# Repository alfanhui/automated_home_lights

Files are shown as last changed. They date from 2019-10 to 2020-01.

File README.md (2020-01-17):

# automated_home_lights
An arduino project to control 3 relay mains switches when entering a room. Controls for current ambient light, detection of direction of travel by a PIR sensor and a door magnet switch. 

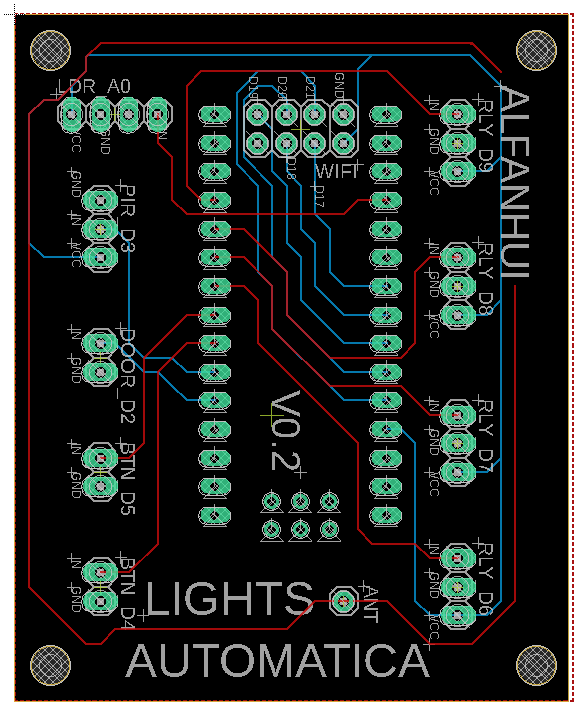
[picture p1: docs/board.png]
Board Schematic


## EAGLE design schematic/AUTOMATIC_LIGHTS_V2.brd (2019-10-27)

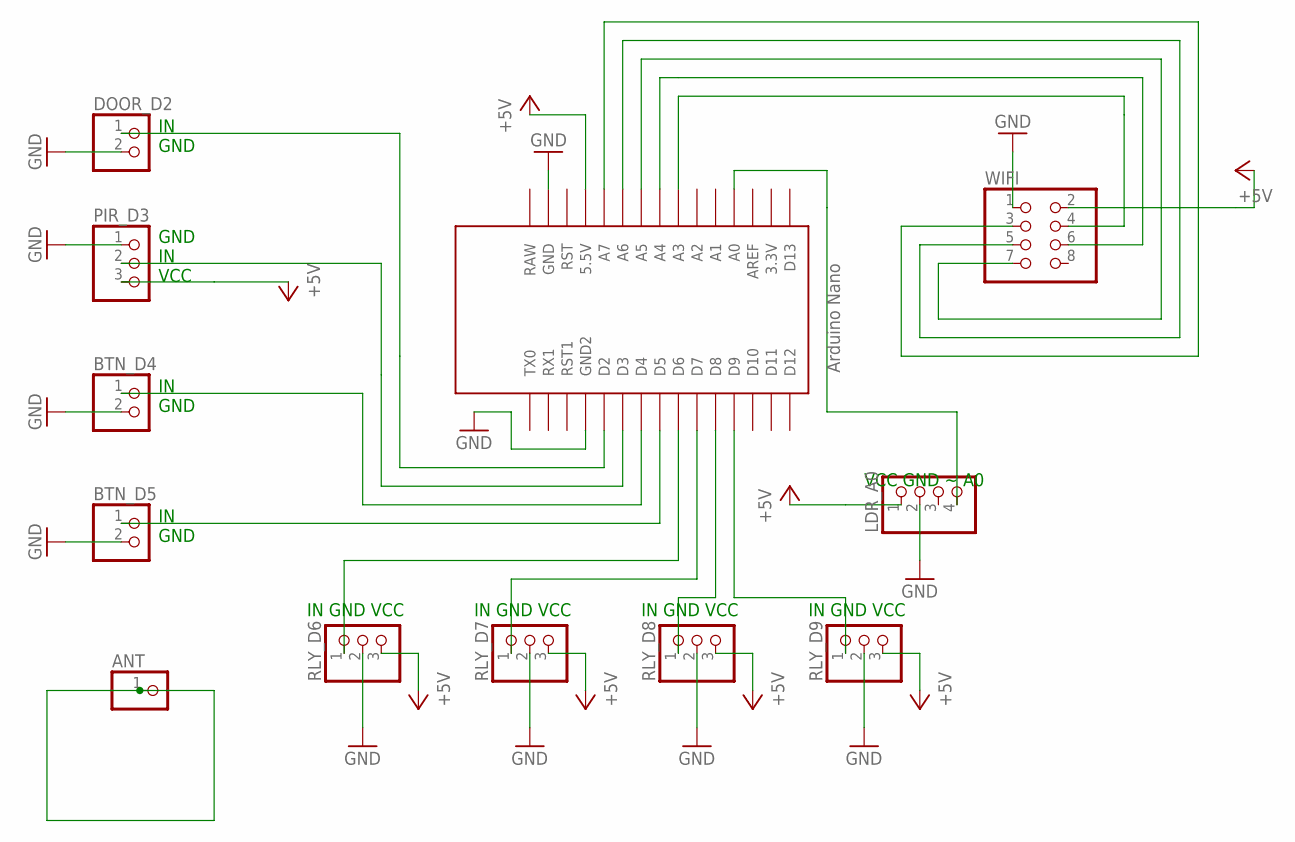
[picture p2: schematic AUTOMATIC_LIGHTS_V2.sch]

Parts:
ANT: PINHD-1X1; 1X01
BTN_D4, BTN_D5: PINHD-1X2; 1X02
DOOR_D2: PINHD-1X2; 1X02
LDR_A0: PINHD-1X4; 1X04
PIR_D3: PINHD-1X3; 1X03
RLY_D6, RLY_D7, RLY_D8, RLY_D9: PINHD-1X3; 1X03
U$1: NANO
WIFI: PINHD-2X4; 2X04

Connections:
+5V: LDR_A0.1, PIR_D3.3, RLY_D6.3, RLY_D7.3, RLY_D8.3, RLY_D9.3, U$1.5V (5.5V), WIFI.2
GND: BTN_D4.2, BTN_D5.2, DOOR_D2.2, LDR_A0.2, PIR_D3.1, RLY_D6.2, RLY_D7.2, RLY_D8.2, RLY_D9.2, U$1.GND, U$1.GND1 (GND2), WIFI.1
unnamed: LDR_A0.4, U$1.A0
unnamed: BTN_D4.1, U$1.D4
unnamed: BTN_D5.1, U$1.D5
unnamed: DOOR_D2.1, U$1.D2
unnamed: PIR_D3.2, U$1.D3
unnamed: RLY_D6.1, U$1.D6
unnamed: RLY_D7.1, U$1.D7
unnamed: RLY_D8.1, U$1.D8
unnamed: RLY_D9.1, U$1.D9
unnamed: U$1.A7, WIFI.3
unnamed: U$1.A6, WIFI.5
unnamed: U$1.A5, WIFI.7
unnamed: U$1.A3, WIFI.4
unnamed: U$1.A4, WIFI.6

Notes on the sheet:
IN GND VCC
IN GND
VCC GND ~ A0
GND IN VCC

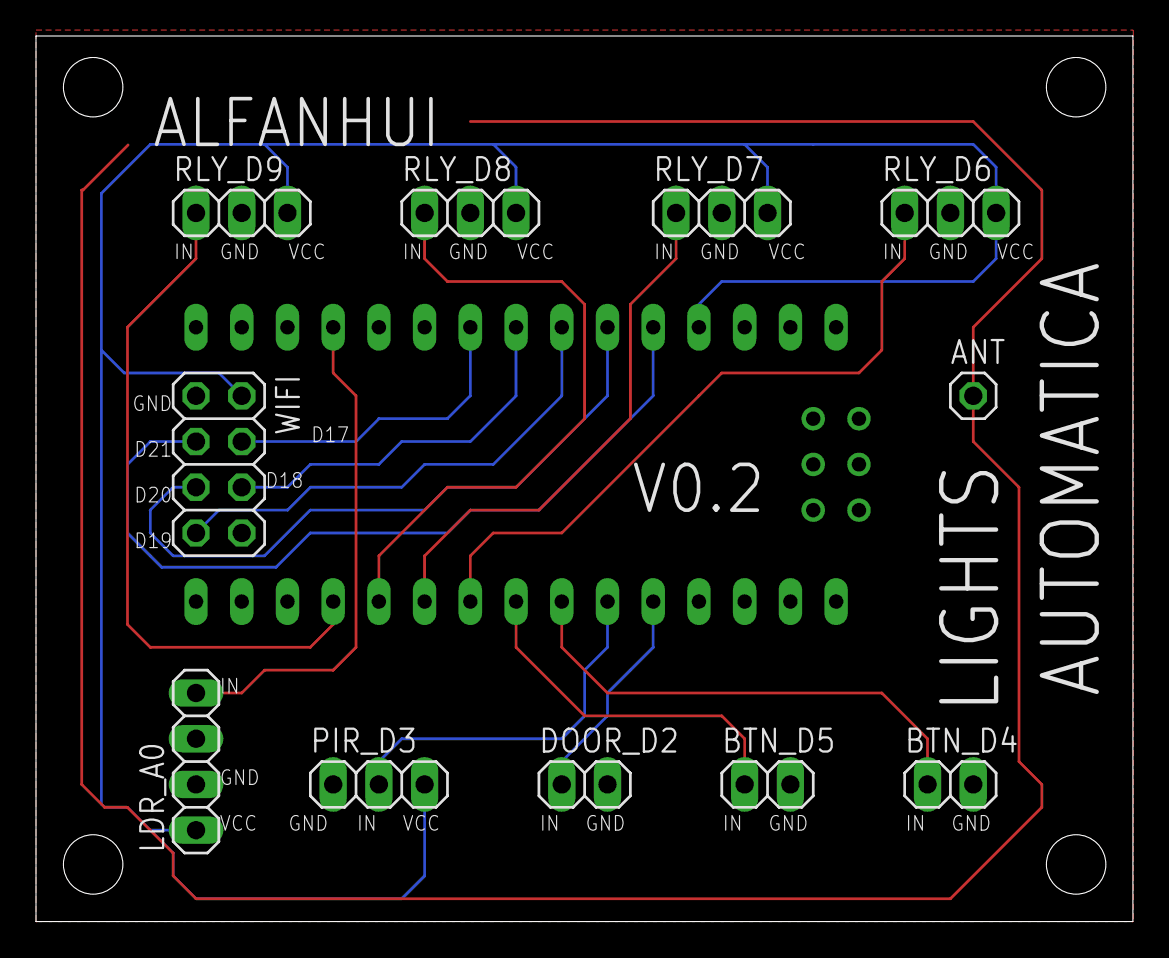
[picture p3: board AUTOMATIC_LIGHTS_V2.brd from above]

Board: 2 copper layers, 60.9 x 49.2 mm, 12 parts (1 on the bottom side), 16 nets.

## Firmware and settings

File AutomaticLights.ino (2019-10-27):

/*
   Written by Stuart Huddy on 13th of March, 2018
   Equipment: Arduino Uno,
              3x 5v relay switches,
              PIR sensor,
              PhotoCell sensor,
              Magnet Door switch,
              Master Button,
              Mini breadboard
   Using the Door magnet with a PIR sensor on one side of the door, I determin the direction of movement
   by checking which action happened first between the PIR and door magenet.
   I have 3 relays, one controlling the main light switch, and 2 lamps for chilled lighting. The chilled
   lighting turns on after a minute and a half of entering the room.
*/


#include <elapsedMillis.h>

//Pin values
const int LIGHT_DETECT_PIN = A0;
const int BUTTON = 12;
const int PIR_PIN = 3;
const int DOOR_PIN = 2;
const int RELAY_MAIN_PIN = 7;
const int RELAY_LAMP1_PIN = 8;
const int RELAY_LAMP2_PIN = 10;


//temp varaibles
unsigned int light_detect_raw = 0;
int button_state = 0;
int pir_raw = 0;
int door_state = 0;

//deciders
bool lights_on = false;  //True when lights are on
bool entered = true;     //True when someone enteres
bool hasLeft = true;     //True when someone leaves, if not reactivated by motion in room
bool initalLightStage = false; //True when first light is turned on

//Timelogs
#define ONE_HALF 90000  //1.5 minutes in milliseconds
#define THREE 180000  //3 minutes in milliseconds
#define NINE 540000 //9 minutes in milliseconds
#define TEN 600000  //10 minutes in milliseconds
#define ELEVEN 660000  //11 minutes in milliseconds
#define THIRTEEN 780000 //13 minutes in milliseconds
#define TOO_DARK 800 //Photosensor trigger  (900 dark, 180 bright)
elapsedMillis timeElapsed_door = 1000;
elapsedMillis timeElapsed_pir;
elapsedMillis timeElapsed_forLampSwitchOver;
elapsedMillis timeElapsed_afterLeaving = 200000;

void setup() {
  Serial.begin(9600);
  //PIR
  attachInterrupt(digitalPinToInterrupt(PIR_PIN), motion_detected, RISING);
  //RELAY
  pinMode(RELAY_MAIN_PIN, OUTPUT);
  pinMode(RELAY_LAMP1_PIN, OUTPUT);
  pinMode(RELAY_LAMP2_PIN, OUTPUT);
  digitalWrite(RELAY_MAIN_PIN, LOW);
  digitalWrite(RELAY_LAMP1_PIN, LOW);
  digitalWrite(RELAY_LAMP2_PIN, LOW);
  //DOOR
  pinMode(DOOR_PIN, INPUT);
  //LIGHT
  pinMode(LIGHT_DETECT_PIN, INPUT);
  //BUTTON
  pinMode(BUTTON, INPUT_PULLUP);
}

void loop() {  
  //printValues();
  //Check state of button
    if(button_state != digitalRead(BUTTON)){
      button_state = digitalRead(BUTTON);
       if(button_state == LOW){
        button_pressed();
      }
    }
    
  //Check if door state has changed.
  if (door_state != digitalRead(DOOR_PIN)) {
    door_state = digitalRead(DOOR_PIN);
    if (door_state == HIGH) {
      timeElapsed_door = 0;
      //Serial.println("DOOR OPEN");
    } else {
      //Serial.println("DOOR CLOSED");
    }
  }

  //Determin movement direction
  if (entered && timeElapsed_door < timeElapsed_pir) {
    //Serial.println("you left the room");
    entered = false;
    if (lights_on) {
      timeElapsed_afterLeaving = 0;
      hasLeft = true;
    }
  } else if (!entered && timeElapsed_door > timeElapsed_pir) {
    int diffBetweenSensors = timeElapsed_door - timeElapsed_pir;
    if(diffBetweenSensors < ELEVEN){ //Stops random shakes of sensor tripping sensor, or wakes in the night
      //Serial.println("you entered the room");
      entered = true;
      if (lights_on) {
        hasLeft = false;
        timeElapsed_afterLeaving = 200000;
      } else {
        if (checkIfDarkEnough()) {
          lights_on = true;
          turnOnMainLighting();
          timeElapsed_forLampSwitchOver = 0;
          initalLightStage = true;
        }
      }
    }
  }

  //Switches to chilled lighting
  if (lights_on && initalLightStage && timeElapsed_forLampSwitchOver > ONE_HALF) {
    turnOnChilledLighting();
  }

  //Switches lights off after leaving
  if (!entered && lights_on && hasLeft && timeElapsed_afterLeaving > TEN) {
    turnOffLighting(true);
    initalLightStage = true;
    hasLeft = false;
    lights_on = false;
  }
}

bool checkIfDarkEnough(){
  light_detect_raw = analogRead(LIGHT_DETECT_PIN);
  //Serial.println(light_detect_raw);
  return (light_detect_raw > TOO_DARK);
}

void turnOnMainLighting(){
     //Serial.println("Turning main lights on");
     digitalWrite(RELAY_MAIN_PIN, HIGH);
}

void turnOnChilledLighting(){
    //Serial.println("Turning chillded lights on");
    digitalWrite(RELAY_LAMP2_PIN, HIGH);
    delay(500); //for effect?
    digitalWrite(RELAY_LAMP1_PIN, HIGH);
    delay(500);
    digitalWrite(RELAY_MAIN_PIN, LOW);
}

void turnOffLighting(bool slowly){
    //Serial.println("Turning all lights off");
    digitalWrite(RELAY_MAIN_PIN, LOW);
    if(slowly) delay(500);
    digitalWrite(RELAY_LAMP1_PIN, LOW);
    if(slowly) delay(500);
    digitalWrite(RELAY_LAMP2_PIN, LOW);
}


//Is called when motion is detected
void motion_detected() {
  //Serial.println("Motion detected");
  if(timeElapsed_door < 6000){
    timeElapsed_pir = 0;
  }
  if(timeElapsed_afterLeaving < THIRTEEN && timeElapsed_afterLeaving > TEN){
    if(checkIfDarkEnough()){
      timeElapsed_pir = 0;
      hasLeft = false;
      turnOnChilledLighting();
      lights_on = true;
    }
  }
  if (lights_on) {
    timeElapsed_pir = 0;
    hasLeft = false;
  }
}

void button_pressed() {
  //Serial.println("Button has been pressed");
  if (lights_on) {
    turnOffLighting(false);
    delay(2000); //Delay to give a chance to block sensor turning lights back on.
    button_state = HIGH;
    entered = false;
    timeElapsed_afterLeaving = ELEVEN;
    timeElapsed_door = 7001;
    timeElapsed_pir = 18000;
    lights_on = false;
  } else {
    turnOnChilledLighting();
    entered = true;
    lights_on = true;
  }
  initalLightStage = false;
  hasLeft = false; //we want this false here so the lights do not reactivate through motion instantly.
  timeElapsed_afterLeaving = 200000;
}


void printValues(){
  Serial.println("timeElapsed_door : timeElapsed_pir : timeElapsed_forLampSwitchOver : timeElapsed_afterLeaving"); 
  Serial.print(timeElapsed_door);
  Serial.print(" : "); 
  Serial.print(timeElapsed_pir);
  Serial.print(" : "); 
  Serial.print(timeElapsed_forLampSwitchOver);
  Serial.print(" : "); 
  Serial.print(timeElapsed_afterLeaving);
  Serial.println();
  Serial.println("lights_on : entered : hasLeft : initialLightStage"); 
  Serial.print(lights_on);
  Serial.print(" : "); 
  Serial.print(entered);
  Serial.print(" : "); 
  Serial.print(hasLeft);
  Serial.print(" : "); 
  Serial.print(initalLightStage);
  Serial.println();
  Serial.println("button_state : light_detect_raw : door_state");
  button_state = digitalRead(BUTTON);
  light_detect_raw = analogRead(LIGHT_DETECT_PIN);
  door_state = digitalRead(DOOR_PIN);
  Serial.print(button_state);
  Serial.print(" : "); 
  Serial.print(light_detect_raw);
  Serial.print(" : "); 
  Serial.print(door_state); 
  Serial.println();
}

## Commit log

2018-03-14 First draft, button code untested as not currently wired.
2018-03-25 Added the button to the circuit, updated button code to work better
2018-04-09 Checked the difference between sensors when detected entered room. Should stop random house shuddering or ghosts from activating the sensor causing it to think someone has entered the room.
2018-04-14 Still coming home to lights on. Its either because the direction of travel is not confirmed and therefore gets triggered, or that the values are not reset correctly when operating master switch. Hope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
    [AutomaticLights.ino]
2018-06-03 Clean up some variable resets. Hopefully bug fixed re: motion not detecting someone is still in room when someone else has left (and for the lights to remain on).
    [AutomaticLights.ino]
2018-06-05 3 conditions added to the button. if the light has been detected within a minute of door opening(generous timing) -> reset timer (to turn on lights), or if the hasLeft timer is between 9 and 13 minut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
    [AutomaticLights.ino]
2018-06-12 Previous commit was had the wrong bool value set.
    [AutomaticLights.ino]
2018-06-13 Refactoring, previous previous previous commit never actually worked, so hopefully when the sensor thinks I've left but then detects me in the room, it will switched to the cool chilled moood lightin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
2019-10-27 Added updated program that has TOO_DARK var and adjustments to lights turning back when they shouldn't
    [AUTOMATIC_LIGHTS_V2.brd, AUTOMATIC_LIGHTS_V2.sch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]
2020-01-17 Updated gitignore and added photo of schematic
